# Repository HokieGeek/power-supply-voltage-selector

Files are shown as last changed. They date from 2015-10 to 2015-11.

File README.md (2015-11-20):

# power-supply-voltage-selector 
Trying to learn more electronics by building a circuit that lets me have different voltage outputs for use with other prototypes and mostly breadboards

## Prototype
Current progress

# Schematics
## Primary
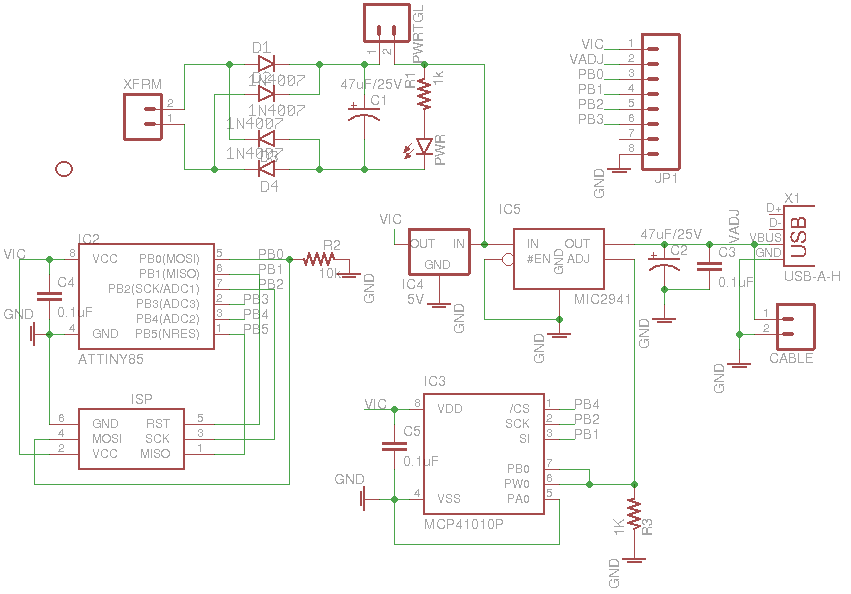
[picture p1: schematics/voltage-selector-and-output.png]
Logic schematics

## Daughter
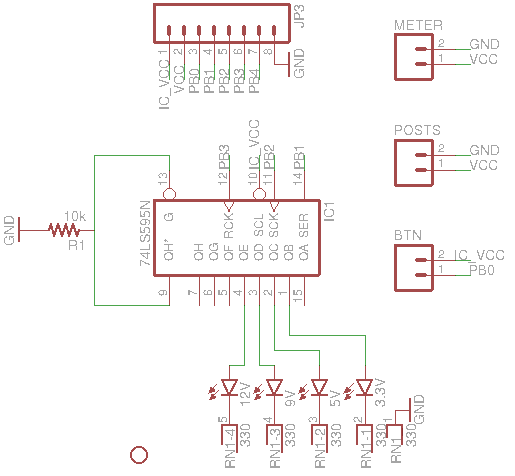
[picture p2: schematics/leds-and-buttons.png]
LEDs and Buttons


# Boards
## Primary
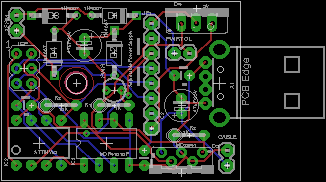
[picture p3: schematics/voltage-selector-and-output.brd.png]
Main board

## Daughter
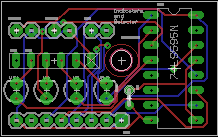
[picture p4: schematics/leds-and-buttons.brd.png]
Board of LEDs and Buttons


# Parts list
## ICs
* [ATTINY85](http://www.atmel.com/images/atmel-2586-avr-8-bit-microcontroller-attiny25-attiny45-attiny85_datasheet.pdf) - Drives the digi pot and shift register
* [LM7805CT](http://www.mouser.com/ds/2/149/LM7805-189995.pdf) - 5v voltage regulator for Vic
* [MIC2940](http://www.micrel.com/_PDF/mic2940.pdf) - Adjustable voltage regulator as target output regulator
* [MCP41010](http://ww1.microchip.com/downloads/en/DeviceDoc/11195c.pdf) - 10 kΩ digital potentiometer
* [SN74LS595N](http://www.ti.com/lit/ds/symlink/sn74ls596.pdf) - 8-bit shift registers with latches

## Discrete components
* 12V Transformer
* 4x 1N4007 Rectifiers
* 2x 47 µF Electrolytic capacitors
* 3x 0.1 µF Ceramic capacitors
* 1x 330 Ω Resistor network (SIL-6)
* 1x 10 kΩ 5% Resistors
* 2x 1 kΩ 5% Resistors
* 4x 3mm LEDs (green. To indicate selected voltage)
* 1x 3mm LED (red. To indicate that power is flowing from the wall)
* 1x USB-A Female
* LED Volt meter thingy (slightly redundant with the LEDs...)
* Toggle switch (turns on Vin)
* Momentatry switch (selects voltage)
* Jumpers and headers (Oh my!)

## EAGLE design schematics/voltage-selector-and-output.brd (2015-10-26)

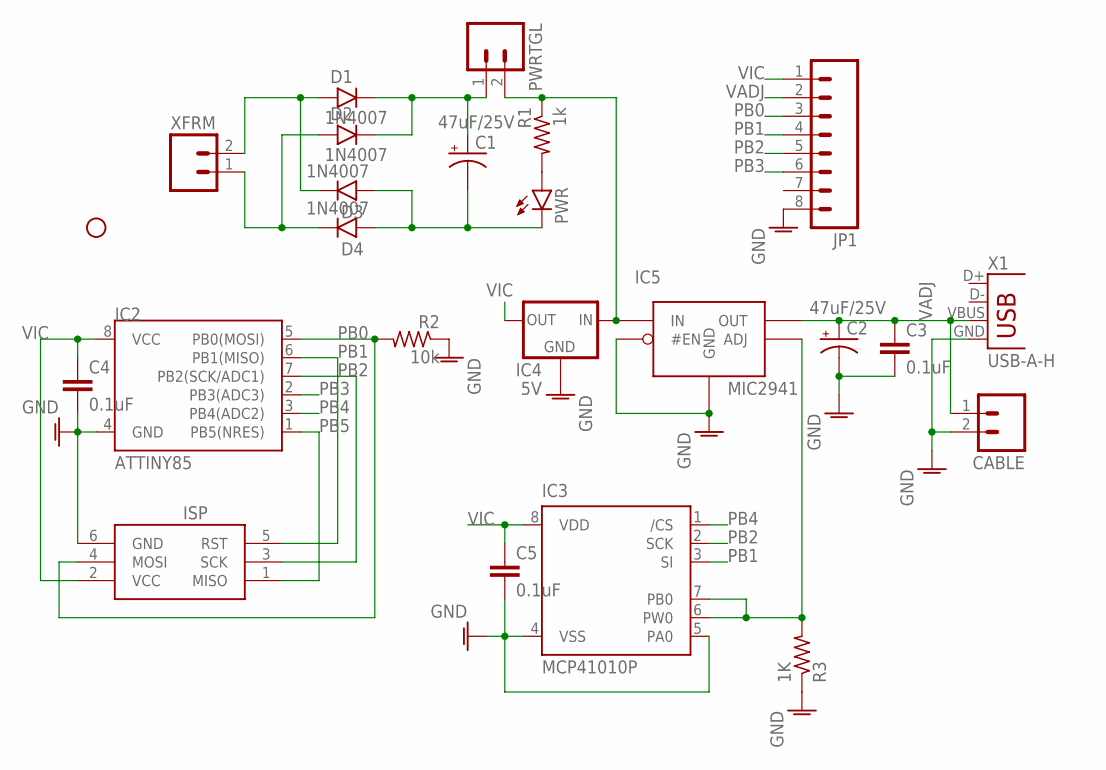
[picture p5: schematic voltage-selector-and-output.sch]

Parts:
C1, C2: 47uF/25V; E2,5-6
C3, C4, C5: 0.1uF; CAP-PTH-SMALL
CABLE: M02PTH; 1X02
D1, D2, D3, D4: 1N4007; DO41-3
IC2: ATTINY85; DIP08
IC3: MCP41010P; DIL8
IC4: 5V; 78XXS
IC5: MIC2941; TO220-5
ISP: AVRISP-6; AVRISP
JP1: M081X08; 1X08
PWR: LED-3MM-NO_SILK; LED3MM-NS
PWRTGL: M02PTH; 1X02
R1: 1k; 0207/5V
R2: 10k; 0207/5V
R3: 1K; 0207/5V
STANDOFF1: STAND-OFF
X1: USB-A-H
XFRM: M02PTH; 1X02

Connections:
AGND: C2.-, C3.2, C4.2, C5.2, CABLE.2, IC2.4 (GND), IC3.4 (VSS), IC3.5 (PA0), IC4.GND, IC5.2 (#EN), IC5.3 (GND), ISP.6 (GND), JP1.8, R2.1, R3.1, X1.GND
GND: D2.A, D4.C, XFRM.1
unnamed: IC3.6 (PW0), IC3.7 (PB0), IC5.1 (ADJ), R3.2
unnamed: D1.A, D3.C, XFRM.2
unnamed: C1.-, D3.A, D4.A, PWR.K (C)
unnamed: C1.+, D1.C, D2.C, PWRTGL.1
unnamed: PWR.A, R1.2
PB0: IC2.5 (PB0(MOSI)), ISP.4 (MOSI), JP1.3, R2.2
PB1: IC2.6 (PB1(MISO)), IC3.3 (SI), ISP.5 (RST), JP1.4
PB2: IC2.7 (PB2(SCK/ADC1)), IC3.2 (SCK), ISP.3 (SCK), JP1.5
PB3: IC2.2 (PB3(ADC3)), JP1.6
PB4: IC2.3 (PB4(ADC2)), IC3.1 (/CS)
PB5: IC2.1 (PB5(NRES)), ISP.1 (MISO)
VADJ: C2.+, C3.1, CABLE.1, IC5.5 (OUT), JP1.2, X1.VBUS
VCC: IC4.IN, IC5.4 (IN), PWRTGL.2, R1.1
VIC: C4.1, C5.1, IC2.8 (VCC), IC3.8 (VDD), IC4.OUT, ISP.2 (VCC), JP1.1

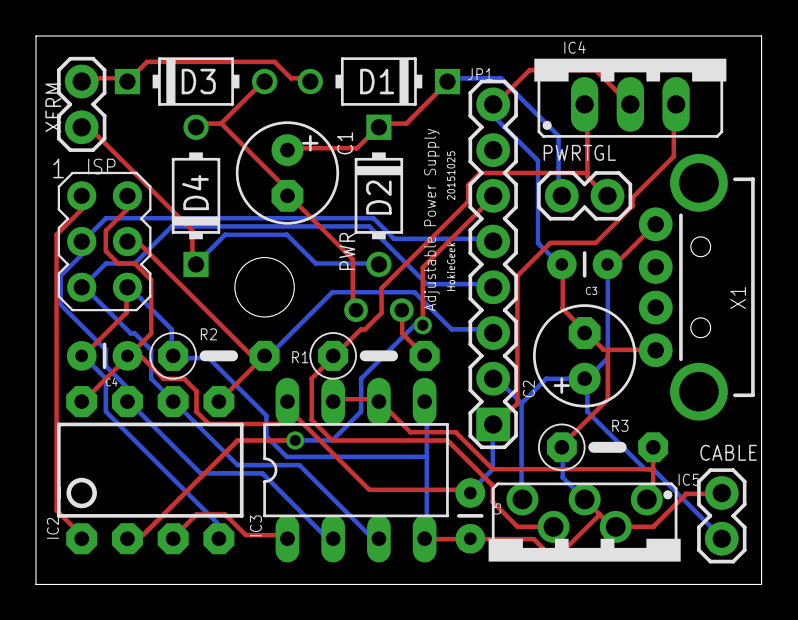
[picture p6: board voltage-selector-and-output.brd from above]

Board: 2 copper layers, 40.3 x 30.5 mm, 24 parts (0 on the bottom side), 16 nets.

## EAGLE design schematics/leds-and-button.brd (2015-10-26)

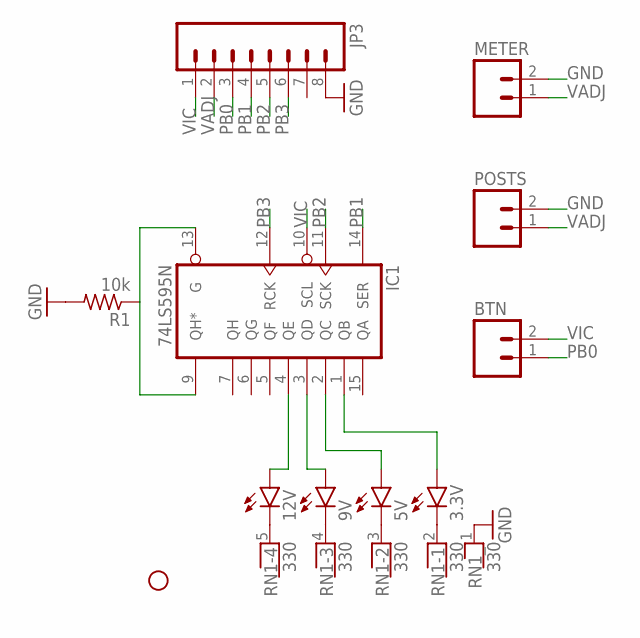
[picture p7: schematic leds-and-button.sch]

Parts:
3.3V, 5V, 9V, 12V: LED3MM
BTN: M02PTH; 1X02
IC1: 74LS595N; DIL16
JP2: STAND-OFF
JP3: M081X08; 1X08
METER: M02PTH; 1X02
POSTS: M02PTH; 1X02
R1: 10k; 0204V
RN1: 330; RN-6

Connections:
GND: IC1.8 (GND), JP3.8, METER.2, POSTS.2, R1.2, RN1.1
unnamed: 12V.K (C), RN1.5
unnamed: 9V.K (C), RN1.4
unnamed: 12V.A, IC1.4 (QE)
unnamed: 9V.A, IC1.3 (QD)
unnamed: 5V.A, IC1.2 (QC)
unnamed: 5V.K (C), RN1.3
unnamed: 3.3V.K (C), RN1.2
unnamed: IC1.9 (QH*), IC1.13 (G), R1.1
unnamed: 3.3V.A, IC1.1 (QB)
PB0: BTN.1, JP3.3
PB1: IC1.14 (SER), JP3.4
PB2: IC1.11 (SCK), JP3.5
PB3: IC1.12 (RCK), JP3.6
VADJ: IC1.16 (VCC), JP3.2, METER.1, POSTS.1
VIC: BTN.2, IC1.10 (SCL), JP3.1

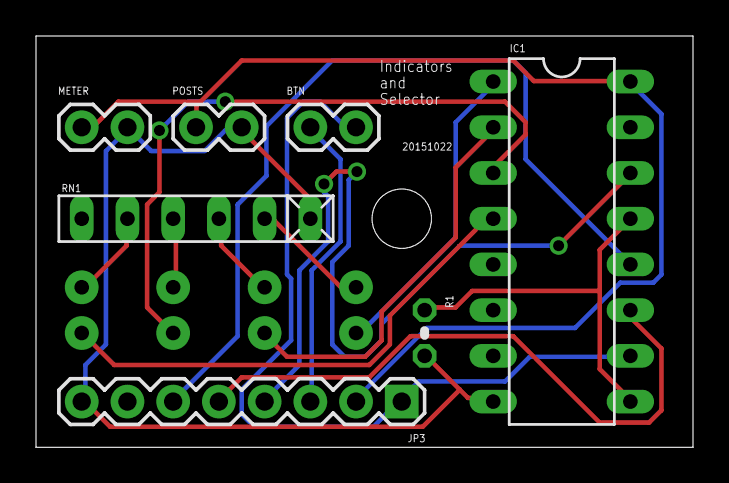
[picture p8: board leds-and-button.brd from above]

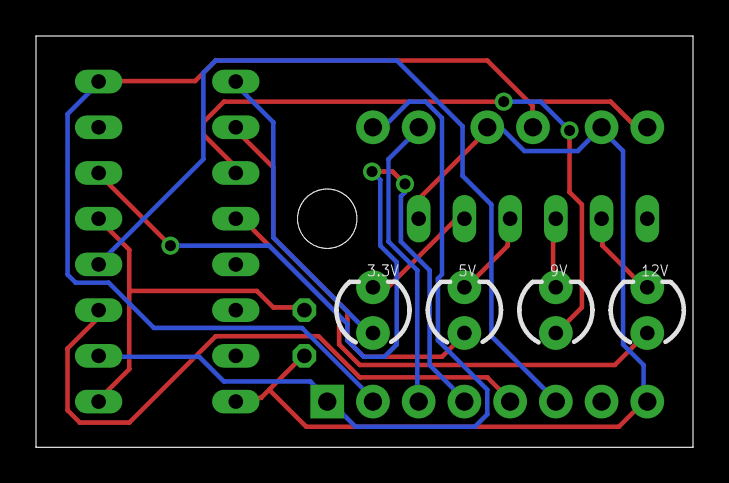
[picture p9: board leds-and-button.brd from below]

Board: 2 copper layers, 36.5 x 22.9 mm, 12 parts (4 on the bottom side), 16 nets.

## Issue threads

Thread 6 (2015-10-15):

Consider a digital pot

HokieGeek, 2015-10-15:
I already have an MCP41010: http://ww1.microchip.com/downloads/en/DeviceDoc/11195c.pdf

HokieGeek, 2015-10-15:
I already have an MCP41010: http://ww1.microchip.com/downloads/en/DeviceDoc/11195c.pdf

HokieGeek, 2015-10-15:
The command byte will always be `0b00010001`

HokieGeek, 2015-10-15:
Bus Pirate command to set it to mid resistance (5k, I guess) should be: `[0x11 0x80]`

HokieGeek, 2015-10-15:
Any point considering shutdown mode (`0b00100001`)?

I can only think that I would use it when I select 'Adjustable' but is there a point in that?

HokieGeek, 2015-10-16:
http://maxembedded.com/2013/11/the-spi-of-the-avr/

HokieGeek, 2015-10-16:
Atmel's AVR and SPI doc: http://www.atmel.com/images/doc2585.pdf

HokieGeek, 2015-10-16:
This works...

http://henrysbench.capnfatz.com/henrys-bench/mcp41010-digital-potentiometer-arduino-user-manual/

HokieGeek, 2015-10-16:
Interesting
``` Arduino
SPI.transfer16(val16)
```
https://www.arduino.cc/en/Reference/SPITransfer

HokieGeek, 2015-10-16:
I should probably determine if I can even do what I want to do. From the regulator's datasheet:

VOUT = VREF x { 1 + R1/R2 } – |IFB| R1

HokieGeek, 2015-10-18:
Figure out how well the shutdown mode for this works

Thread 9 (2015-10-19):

Use PB0 as output

HokieGeek, 2015-10-19:
Try it out with a blinky, but should be able to send output to the transistor... Would be nice if it was a latching transistor...

Holy crap! Section 10.2.1 of the tiny85 sheet says that it has internal pull-up resistors! I could configure the button so that it won't need its own resistor!
``` c
 // Pull-up resistor should turn on with the following config
DDRB |= (1 << DDB0);
PORTB |= (1 << PB0);
```

HokieGeek, 2015-10-22:
For what I'm doing, a pull-down resistor makes more sense, so don't try to use the pull-ups

Closed 2015-10-25.

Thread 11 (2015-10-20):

Determine why USI didn't work for the pot's SPI

HokieGeek, 2015-10-20:
I would rather not have to resort to bit banging

HokieGeek, 2015-10-20:
Exact example of using USI to drive a 595: https://github.com/JChristensen/tinySPI

HokieGeek, 2015-10-20:
See section 15 of the attiny85 datasheet

HokieGeek, 2015-10-20:
USICS0 = 1

HokieGeek, 2015-10-20:
Create a USI class that SPI wraps around.

Need
- USI three-wire [USCK, DO, DI]     (which SPI will wrap this one.)
- USI two-wire [SCL,SDA]

HokieGeek, 2015-10-22:
http://www.atmel.com/Images/doc2582.pdf

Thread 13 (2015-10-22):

Use timer/counter for double-click

HokieGeek, 2015-10-22:
See section 11 of the datasheet

HokieGeek, 2015-10-22:
### Approach #1
Set a delay value between clicks that is appropriate
When clicked,
 if counter value is 0
     set up counter that counts down from that value
else
     record double click

HokieGeek, 2015-10-22:
### Second approach
Start countdown that, when it reaches 0, interrupts with a double-click

HokieGeek, 2015-10-22:
http://www.ganssle.com/debouncing-pt2.htm

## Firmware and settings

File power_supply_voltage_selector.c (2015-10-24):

#define F_CPU 8000000UL

#include <avr/io.h>
#include <avr/interrupt.h>
#include <avr/sleep.h>
#include <util/delay.h>

#include "eeprom.h"
#include "shiftregister.h"
#include "spi.h"

//#define TIMER_PRESCALE ~(1<<WDP0)&~(1<<WDP1)&~(1<<WDP2)&~(1<<WDP3) // 16ms
#define TIMER_PRESCALE_MILLIS 16
//#define TIMER_PRESCALE (1<<WDP0) // 32ms
//#define TIMER_PRESCALE_MILLIS 32
//#define TIMER_PRESCALE (1<<WDP1) // 64ms
//#define TIMER_PRESCALE_MILLIS 64
//#define TIMER_PRESCALE (1<<WDP1) | (1<<WDP0) // 1/8s
//#define TIMER_PRESCALE_MILLIS 125
//#define TIMER_PRESCALE (1<<WDP2) // 1/4s
//#define TIMER_PRESCALE_MILLIS 250
//#define TIMER_PRESCALE (1<<WDP2) | (1<<WDP0) // 1/2s
//#define TIMER_PRESCALE_MILLIS 500
#define TIMER_TIMEOUT 2000 // 2s

#define BTN_DEBOUNCE_DELAY_MILLIS 25
#define BTN_DOUBLE_CLICK_DELAY_MILLIS 200
#define BUTTON_PIN PB0

#define HC595_PIN_DATA PB1
#define HC595_PIN_LATCHCLOCK PB3
#define HC595_PIN_SHIFTCLOCK PB2

#define MCP41010_PIN_DATA PB1
#define MCP41010_PIN_SERIALCLOCK PB2
#define MCP41010_PIN_CHIPSELECT PB4

#define MCP4XXXX_POT_0 0
#define MCP4XXXX_POT_1 1
#define MCP4XXXX_COMMAND_P0_WRITE 0b00010001
#define MCP4XXXX_COMMAND_P0_SHUTDOWN 0b00100001

#define NUM_VOLTAGE_SELECTIONS 4
#define SELECTED_VOLTAGE_EEPROM_ADDRESS 0b01000000

typedef struct {
    uint8_t led;
    uint8_t potData;
} VoltageSelection;

uint8_t currentVoltageSelection = 0;
VoltageSelection* voltageSelections;

ShiftRegister *shiftReg;
SpiDevice *spi;

typedef struct {
    int pinId;
    long lastReleaseTime;
    long lastDebounceTime;
    int state;
    int clickCount;
    void (*handler)(int, int, int);
} BUTTON_ITEM;

BUTTON_ITEM* handledButtons;

// ================ TIME ================ //
long elapsedTime = 0;
uint8_t timerEnabled = 0;

long clock_diff(long old_clock, long new_clock) {
  if (new_clock >= old_clock)
    return new_clock - old_clock;
  else
    return new_clock + (65535 - old_clock);
}

// ================ BUTTONS ================ //
BUTTON_ITEM* debouncedButton(int pin) {
    BUTTON_ITEM* btn = &handledButtons[pin];

    if (timerEnabled == 0) {
        startTimer();
        btn->lastDebounceTime = 0;
        btn->lastReleaseTime = 0;
    }

    int currentState = (PINB & (1 << btn->pinId));

    cli();
    long time = elapsedTime;
    sei();

    if (currentState != btn->state) {
        btn->lastDebounceTime = time;
    } 

    if (!currentState) {
    // if (bit_is_clear(PINB, btn->pinId)) {
        btn->lastReleaseTime = time;
    }

    // if ((btn->lastDebounceTime > 0 && time > btn->lastDebounceTime) && ((time - btn->lastDebounceTime) >= BTN_DEBOUNCE_DELAY_MILLIS)) {
        btn->state = currentState;
        if ((btn->lastReleaseTime > 0 && time > btn->lastReleaseTime) && ((time - btn->lastReleaseTime) <= BTN_DOUBLE_CLICK_DELAY_MILLIS)) {
        // if ((time - btn->lastReleaseTime) <= BTN_DOUBLE_CLICK_DELAY_MILLIS) {
        // if (clock_diff(btn->lastReleaseTime, time) <= BTN_DOUBLE_CLICK_DELAY_MILLIS) {
            stopTimer();
            btn->clickCount = 2;
        } else {
            btn->clickCount = 1;
        }
    // }

    return btn;
}

void addButton(int pin, void (*handler)(int, int, int)) {
    // FIXME: need to check for range
    handledButtons[pin].pinId = pin;
    handledButtons[pin].lastDebounceTime = 0;
    handledButtons[pin].lastReleaseTime = 0;
    handledButtons[pin].state = 0;
    handledButtons[pin].handler = handler;
    handledButtons[pin].clickCount = 1;
}

void buttonsInit(int numPins) {
    int size = sizeof(BUTTON_ITEM)*numPins;
    handledButtons = (BUTTON_ITEM*)malloc(size);
    memset(handledButtons, 0, size);
}

void startTimer() {
    // Start the WDT
    if (timerEnabled == 0) {
        WDTCR |= (1<<WDIE); // Enable watchdog timer interrupts
        timerEnabled = 1;
    }
}

void stopTimer() {
    // Stop the WDT
    WDTCR &= ~(1<<WDIE); // Disable watchdog timer interrupts
    elapsedTime = 0L;
    timerEnabled = 0;
}

ISR(WDT_vect) {
    elapsedTime += TIMER_PRESCALE_MILLIS;
    if (elapsedTime >= TIMER_TIMEOUT)
        stopTimer();
}

ISR (PCINT0_vect) {
    // FIXME: how on earth can I tell which button was pressed?
    BUTTON_ITEM* btn = debouncedButton(BUTTON_PIN);
    btn->handler(btn->pinId, btn->state, btn->clickCount);
}

void voltageSelectionsInit(int numVoltages) {
    int size = sizeof(VoltageSelection)*numVoltages;
    voltageSelections = (VoltageSelection*)malloc(size);
    memset(voltageSelections, 0, size);

    // Initialize the selections
    //// 3.3v
    voltageSelections[0].led = 0b01000000;
    // voltageSelections[0].led = 0b00000010;
    voltageSelections[0].potData = 43;
    //// 5v
    voltageSelections[1].led = 0b00100000;
    // voltageSelections[1].led = 0b00000100;
    voltageSelections[1].potData = 76;
    //// 9v
    voltageSelections[2].led = 0b00010000;
    // voltageSelections[2].led = 0b00001000;
    voltageSelections[2].potData = 161;
    //// 12v
    voltageSelections[3].led = 0b00001000;
    // voltageSelections[3].led = 0b00010000;
    voltageSelections[3].potData = 224;
}

void setVoltageSelection(int selection) {
    // Adjust the pot
    uint8_t potDataByte = voltageSelections[selection].potData;
    if (potDataByte == 0) {
        MCP41XXX_shutdown(spi);
    } else {
        MCP41XXX_write(spi, potDataByte);
    }

    // Set the LEDs
    ShiftBytes(shiftReg, voltageSelections[selection].led);

    // Store in memory
    currentVoltageSelection = selection;
    EEPROM_write(SELECTED_VOLTAGE_EEPROM_ADDRESS, selection);
}

int nextVoltage() {
    int next = currentVoltageSelection + 1;
    if (next == NUM_VOLTAGE_SELECTIONS) {
        next = 0;
    }
    return next;
}

void buttonHandler(int btnId, int state, int clickCount) {
    switch (btnId) {
    case BUTTON_PIN:
        if (state && clickCount == 2) {
            setVoltageSelection(nextVoltage());
        }
       break;
    }
}

void MCP4XXXX_send(SpiDevice *const dev, uint8_t command, uint8_t data) {
    uint8_t input[2];
    input[0] = command;
    input[1] = data;

    SpiWriteBytes(dev, 2, input);
}

void MCP41XXX_shutdown(SpiDevice *const dev) {
    MCP4XXXX_send(dev, MCP4XXXX_COMMAND_P0_SHUTDOWN, 0b00000000);
}

void MCP41010_shutdown(dev) {
    MCP41XXX_shutdown(dev);
}

void MCP41XXX_write(SpiDevice *const dev, uint8_t value) {
    MCP4XXXX_send(dev, MCP4XXXX_COMMAND_P0_WRITE, value);
}

void MCP41010_write(dev, value) {
    MCP41XXX_write(dev, value);
}

void init_pins() {
    shiftReg = InitShiftRegister(HC595_PIN_DATA, HC595_PIN_LATCHCLOCK, HC595_PIN_SHIFTCLOCK, -1);

    spi = Init3WireSpiDevice(MCP41010_PIN_CHIPSELECT,
                             MCP41010_PIN_SERIALCLOCK,
                             MCP41010_PIN_DATA);

}

void init_interrupts() {
    // Do the interrupts
    GIMSK |= (1<<PCIE); // Pin Change Interrupt Enable
    PCMSK |= (1<<PCINT0); // Turn on interrupt for Pin0

    sei(); // Enable global interrupts 
}

void init() {
    init_pins();

    buttonsInit(1);
    addButton(BUTTON_PIN, &buttonHandler);

    voltageSelectionsInit(NUM_VOLTAGE_SELECTIONS);

    init_interrupts();

    // Set all initial values
    uint8_t currentVoltageSelection = EEPROM_read(SELECTED_VOLTAGE_EEPROM_ADDRESS);
    setVoltageSelection(currentVoltageSelection);
}

int main(void) {
    // 1. Read EEPROM for previous setting, set respective pins to high
    // 2. Go to sleep and wait for a button to be pushed
    // 3. Wake up when a button is pushed
    // 4. Determine which button (decode)
    // 5. If valid, write it to EEPROM
    // 6. Set the pot value
    // 7. Set the LEDs
    // 8. Go back to bed

    init();

    set_sleep_mode(SLEEP_MODE_PWR_DOWN); // Use the Power Down sleep mode

    for (;;) {
        sleep_mode();   // go to sleep and wait for interrupt...
    }
}

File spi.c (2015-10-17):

#include "spi.h"

#include <stdlib.h>

#include <avr/io.h>
#include <avr/interrupt.h>
#include <util/delay.h>

void SetChipSelectHigh(SpiDevice *const dev) {
    PORTB |= (1<<dev->chipSelect);
}

void SetChipSelectLow(SpiDevice *const dev) {
    PORTB &= ~(1<<dev->chipSelect);
}

void ToggleSerialClock(SpiDevice *const dev) {
    PORTB |= (1<<dev->serialClock);
    PORTB &= ~(1<<dev->serialClock);
}

void SpiWriteBytes(SpiDevice *const dev, int numBytes, uint8_t data[]) {
    SetChipSelectLow(dev);
    for (int byte = 0; byte < numBytes; byte++) {
        for (int bit = 7; bit >= 0; --bit) {
            if ((data[byte] & (1 << bit))) {
                PORTB |= (1 << dev->serialDataInput);
            } else {
                PORTB &= ~(1 << dev->serialDataInput);
            }
            ToggleSerialClock(dev);
        }
    }
    SetChipSelectHigh(dev);
}

SpiDevice *const Init3WireSpiDevice(int chipSelect, int serialClock, int serialDataInput) {
    const int sdsize = sizeof(SpiDevice);

    SpiDevice *const dev = (SpiDevice*)malloc(sdsize);
    dev->chipSelect = chipSelect;
    dev->serialClock = serialClock;
    dev->serialDataInput = serialDataInput;

    DDRB |= (1<<dev->chipSelect)|(1<<dev->serialClock)|(1<<dev->serialDataInput);

    SetChipSelectHigh(dev);

    return dev;
}

// While this is pretty great, the attiny85's registers are 8-bit so 
// I can't use it to set the MCP41010's 16-bit registers. Still need to do bit-banging.

/*
void SetChipSelectHigh2(SpiDevice2 *const dev) {
    PORTB |= (1<<dev->chipSelect);
}

void SetChipSelectLow2(SpiDevice2 *const dev) {
    PORTB &= ~(1<<dev->chipSelect);
}

SpiDevice2 *const InitSpiMaster(int chipSelect) {
    const int sdsize = sizeof(SpiDevice2);
    SpiDevice2 *const dev = (SpiDevice2*)malloc(sdsize);
    dev->chipSelect = chipSelect;

    USICR &= ~((1<<USISIE)|(1<<USIOIE)|(1<<USIWM1));
    USICR |= (1<<USIWM0)|(1<<USICS1)|(1<<USICLK);

    // Set SCK and MOSI as output
    DDRB |= (1<<PB2)|(1<<PB0)|(1<<chipSelect);

    SetChipSelectHigh2(dev);

    return dev;
}

uint8_t spiSend(uint8_t data) {
    USIDR = data;
    USISR = (1<<USIOIF);

    asm volatile("nop");
    while (!(USISR & (1<<USIOIF))) USICR |= (1<<USITC);

    return USIDR;
}

uint8_t SpiSend(SpiDevice2 *const dev, uint8_t data) {
    SetChipSelectLow2(dev);

    uint8_t ret = spiSend(data);

    SetChipSelectHigh2(dev);

    return ret;
}

uint8_t SpiSend16(SpiDevice2 *const dev, uint8_t byte1, uint8_t byte2) {
    SetChipSelectLow2(dev);

    uint8_t ret = spiSend(byte1);
    ret = spiSend(byte2);

    SetChipSelectHigh2(dev);
    _delay_ms(500);

    return ret;
}
*/

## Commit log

2013-11-15 Added Eagle schematics for this
    [ac_to_dc.brd, ac_to_dc.sch, leds_and_button.brd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]
2013-11-15 Found more schematics. Go figure
    [ac_to_dc.brd, ac_to_dc.sch, breadboard_power_supply.sch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]
2015-10-09 Cleaning up the mess I left for myself
    [ac_to_dc.brd, ac_to_dc.sch, breadboard_power_supply.sch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]
2015-10-09 Cleaning up the schematics directory
    [ac-to-dc.brd, ac-to-dc.sch, leds-and-button.brd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]
2015-10-13 Rethinking the transformer placement
    [ac-to-dc.brd]
2015-10-14 Reworked the boards
    [ac-to-dc.brd, leds-and-button.brd, leds-and-button.sch]
2015-10-14 Trying to make sense of my head 3 years ago! :)
    [ac-to-dc.brd]
2015-10-14 Added an LED to the ac-to-dc board
    [ac-to-dc.brd, ac-to-dc.sch]
2015-10-16 Creating buttons.h
2015-10-16 Adding code for using the AVR SPI interface
2015-10-17 Got SPI comm to the digi pot working!
2015-10-17 Moved the spi initializer to where it belongs
2015-10-18 Finally updated the primary schematic
    [voltage-selector-and-output.brd, voltage-selector-and-output.sch]
2015-10-18 Changed how I determine the voltage selected
2015-10-18 Changed the pin being used for the pot SI
    [voltage-selector-and-output.brd, voltage-selector-and-output.sch]
2015-10-19 Resized board boundary to what I have room for and removed transistor array
    [voltage-selector-and-output.brd, voltage-selector-and-output.sch]
2015-10-19 Doing the LEDs first now and seeing if that works out (it does not)
2015-10-19 Finally got to working on the main board layout
    [voltage-selector-and-output.brd, voltage-selector-and-output.sch]
2015-10-19 Moved the shift register to the top board since I have more room there and on the bottom board and I get to free up some pins on the jumper
    [ac-to-dc.brd, ac-to-dc.sch, leds-and-button.brd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]
2015-10-19 Doing this instead of working out. Yup
    [voltage-selector-and-output.brd, voltage-selector-and-output.sch]
2015-10-19 Added pic of current progress
2015-10-20 Trying to deconflict the digi pot and register pins
    [voltage-selector-and-output.brd, voltage-selector-and-output.sch]
2015-10-20 LED was all wrong, of course
    [voltage-selector-and-output.brd, voltage-selector-and-output.sch]
2015-10-20 Removed resetting the register on init and only enables a reset pin if provided
    [shiftregister.c]
2015-10-20 Put some actual thought at pin deconflicting
    and I think I got it right this time.
2015-10-20 Fixing an incorrect comment that was misleading
    [power_supply_voltage_selector.c]
2015-10-21 Updated the schematics
    [leds-and-button.brd, leds-and-button.sch, voltage-selector-and-output.brd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]
2015-10-21 Fixing byte order issue in shift register software write
    [shiftregister.c]
2015-10-21 Definitely don't need a reset
    [power_supply_voltage_selector.c]
2015-10-22 Reverted the shift stuff because I guess it works...?
    [power_supply_voltage_selector.c, shiftregister.c]
2015-10-23 Played around with the board for the leds
    [leds-and-button.brd, leds-and-button.sch, voltage-selector-and-output.sch]
2015-10-24 Decided to remove the "adjustable" option because it was kinda useless
    [leds-and-button.brd, leds-and-button.sch, voltage-selector-and-output.brd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]
2015-10-24 Updated the prototype pic
2015-10-25 Optimizing the location of the components on the board and fixing the schematic
    [voltage-selector-and-output.brd, voltage-selector-and-output.sch]
2015-10-25 The 12v regulator was kinda too much, now that I think about it
    [voltage-selector-and-output.brd, voltage-selector-and-output.sch]
2015-10-26 Tweak tweak
    [leds-and-button.brd, leds-and-button.sch, voltage-selector-and-output.brd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]
2015-10-26 Figured out the error in my drawing, finally
    [voltage-selector-and-output.brd, voltage-selector-and-output.sch]

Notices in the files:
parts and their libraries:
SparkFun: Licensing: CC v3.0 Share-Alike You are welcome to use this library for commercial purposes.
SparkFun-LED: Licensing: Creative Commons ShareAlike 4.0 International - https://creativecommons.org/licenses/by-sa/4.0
